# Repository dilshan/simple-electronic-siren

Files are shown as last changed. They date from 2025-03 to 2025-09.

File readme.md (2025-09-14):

# Simple Transistor-Based Electronic Siren

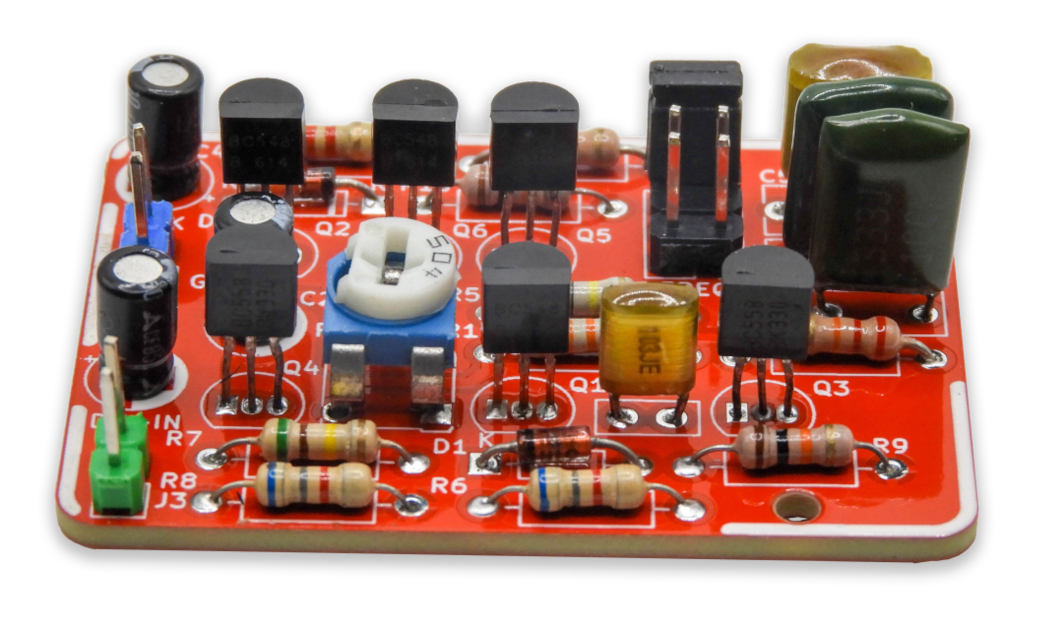
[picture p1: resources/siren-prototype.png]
Finished prototype build of the electronic siren


This project provides a discrete transistor implementation of a multi-tone electronic siren, offering an easy-to-build and low-cost solution that replicates alarm effects found in classic two-timer NE556 siren circuits. It serves as a practical alternative to rare *UM3561* and *UM3562* sound generator ICs.

The design uses only standard *BC548* / *BC558* transistors, resistors, and capacitors—making it easy to build with commonly available components.

A full assembly and test demonstration is available on [YouTube](https://youtu.be/mPkqBXPQGk4). Full details of this project are available at [blog post in here](https://jayakody2000lk.blogspot.com/2025/09/a-simple-transistor-based-electronic.html). 

---

## Features
- Three siren effects
- Adjustable sweep rate via potentiometer
- Operates from **6V** - **12V DC** supply
- Drives a small speaker (16Ω – 32Ω)
- All through-hole components for easy assembly

## PCB
This project PCB was sponsored by **PCBWay**. You can [order the PCB directly from PCBWay’s project sharing space](https://www.pcbway.com/project/shareproject/W282856ASV37_electronic_siren_09_07_2025_0b272f0c.html).

## License
This project is released under the [**Creative Commons Attribution 4.0 International**](https://github.com/dilshan/simple-electronic-siren#CC-BY-4.0-1-ov-file).

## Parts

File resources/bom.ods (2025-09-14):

Designator | Value | Datasheet | Footprint | Qty | Store Link
C1 | 0.033μF | ~ | Capacitor/THT | 1 | https://s.click.aliexpress.com/e/_oDdgOUJ
C2 | 2.2μF / 25V | ~ | Capacitor/THT | 1 | https://s.click.aliexpress.com/e/_oo8At3v
C3 | 0.047μF | ~ | Capacitor/THT | 1 | https://s.click.aliexpress.com/e/_oDdgOUJ
C4,C7 | 10μF / 25V | ~ | Capacitor/THT | 2 | https://s.click.aliexpress.com/e/_oo8At3v
C5 | 0.1μF | ~ | Capacitor/THT | 1 | https://s.click.aliexpress.com/e/_oDdgOUJ
C6 | 0.01μF | ~ | Capacitor/THT | 1 | https://s.click.aliexpress.com/e/_oDdgOUJ
D1,D2 | 1N4148 | https://assets.nexperia.com/documents/data-sheet/1N4148_1N4448.pdf | DO-35 | 2 | https://s.click.aliexpress.com/e/_o2cQ6e7
J1 | 2.54mm 2x3-Pin Header | ~ | Pin Header 2.54mm 2 x 03 | 1 | https://s.click.aliexpress.com/e/_oCfAScX
J2,J3 | 2.54mm 2-Pin Header | ~ | Pin Header 2.54mm 1 x 02 | 2 | https://s.click.aliexpress.com/e/_oCLhFeR
Q1,Q2,Q6 | BC548 | https://www.onsemi.com/pub/Collateral/BC550-D.pdf | TO-92 | 3 | https://s.click.aliexpress.com/e/_onDyZFh
Q3,Q4,Q5 | BC558 | https://www.onsemi.com/pub/Collateral/BC556BTA-D.pdf | TO-92 | 3 | https://s.click.aliexpress.com/e/_onDyZFh
R1 | 33KΩ | ~ | 1/4W Resistor/THT | 1 | https://s.click.aliexpress.com/e/_oEG9d83
R2,R3 | 22KΩ | ~ | 1/4W Resistor/THT | 2 | https://s.click.aliexpress.com/e/_oEG9d83
R4 | 2.2KΩ | ~ | 1/4W Resistor/THT | 1 | https://s.click.aliexpress.com/e/_oEG9d83
R5 | 100KΩ | ~ | 1/4W Resistor/THT | 1 | https://s.click.aliexpress.com/e/_oEG9d83
R6,R8 | 6.8KΩ | ~ | 1/4W Resistor/THT | 2 | https://s.click.aliexpress.com/e/_oEG9d83
R7 | 150KΩ | ~ | 1/4W Resistor/THT | 1 | https://s.click.aliexpress.com/e/_oEG9d83
R9,R10 | 10KΩ | ~ | 1/4W Resistor/THT | 2 | https://s.click.aliexpress.com/e/_oEG9d83
RV1 | 500KΩ | ~ | RM-065 Vertical | 1 | https://s.click.aliexpress.com/e/_oEEE6pv
SPK1 | 16Ω – 32Ω Speaker | ~ | ~ | 1 | https://s.click.aliexpress.com/e/_oCOTR2n
J1-CAP | Jumper Cap |  | 2.54mm Jumper Cap | 1 | https://s.click.aliexpress.com/e/_oCLhFeR

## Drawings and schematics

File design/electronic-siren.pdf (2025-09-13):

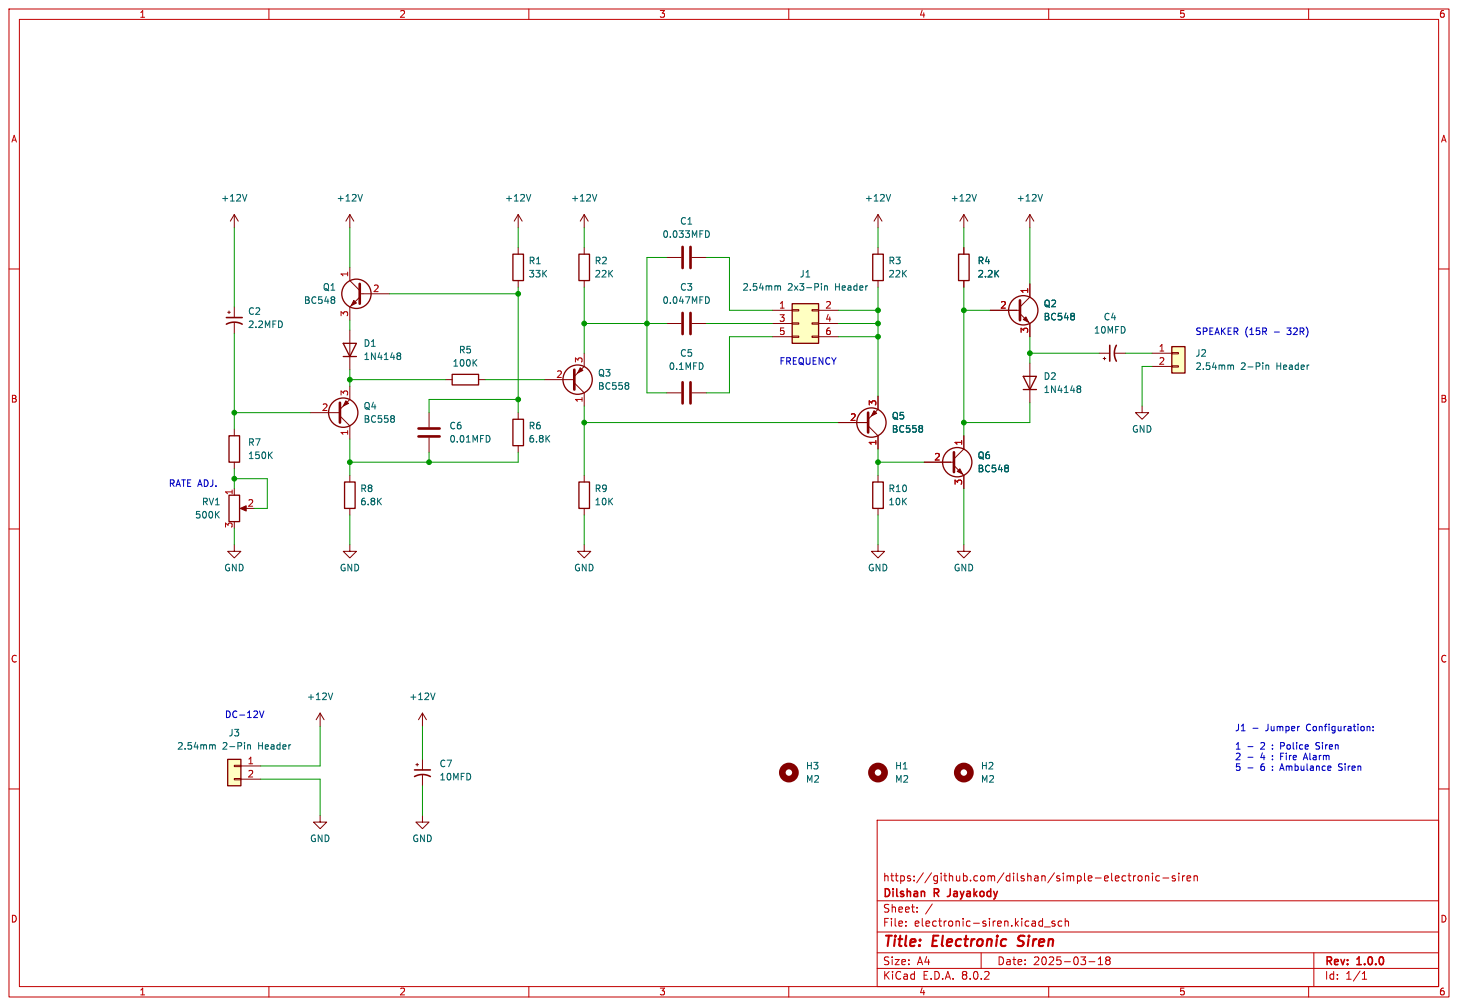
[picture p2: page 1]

https://github.com/dilshan/simple-electronic-siren R8

Id: 1/1 Title: Electronic Siren

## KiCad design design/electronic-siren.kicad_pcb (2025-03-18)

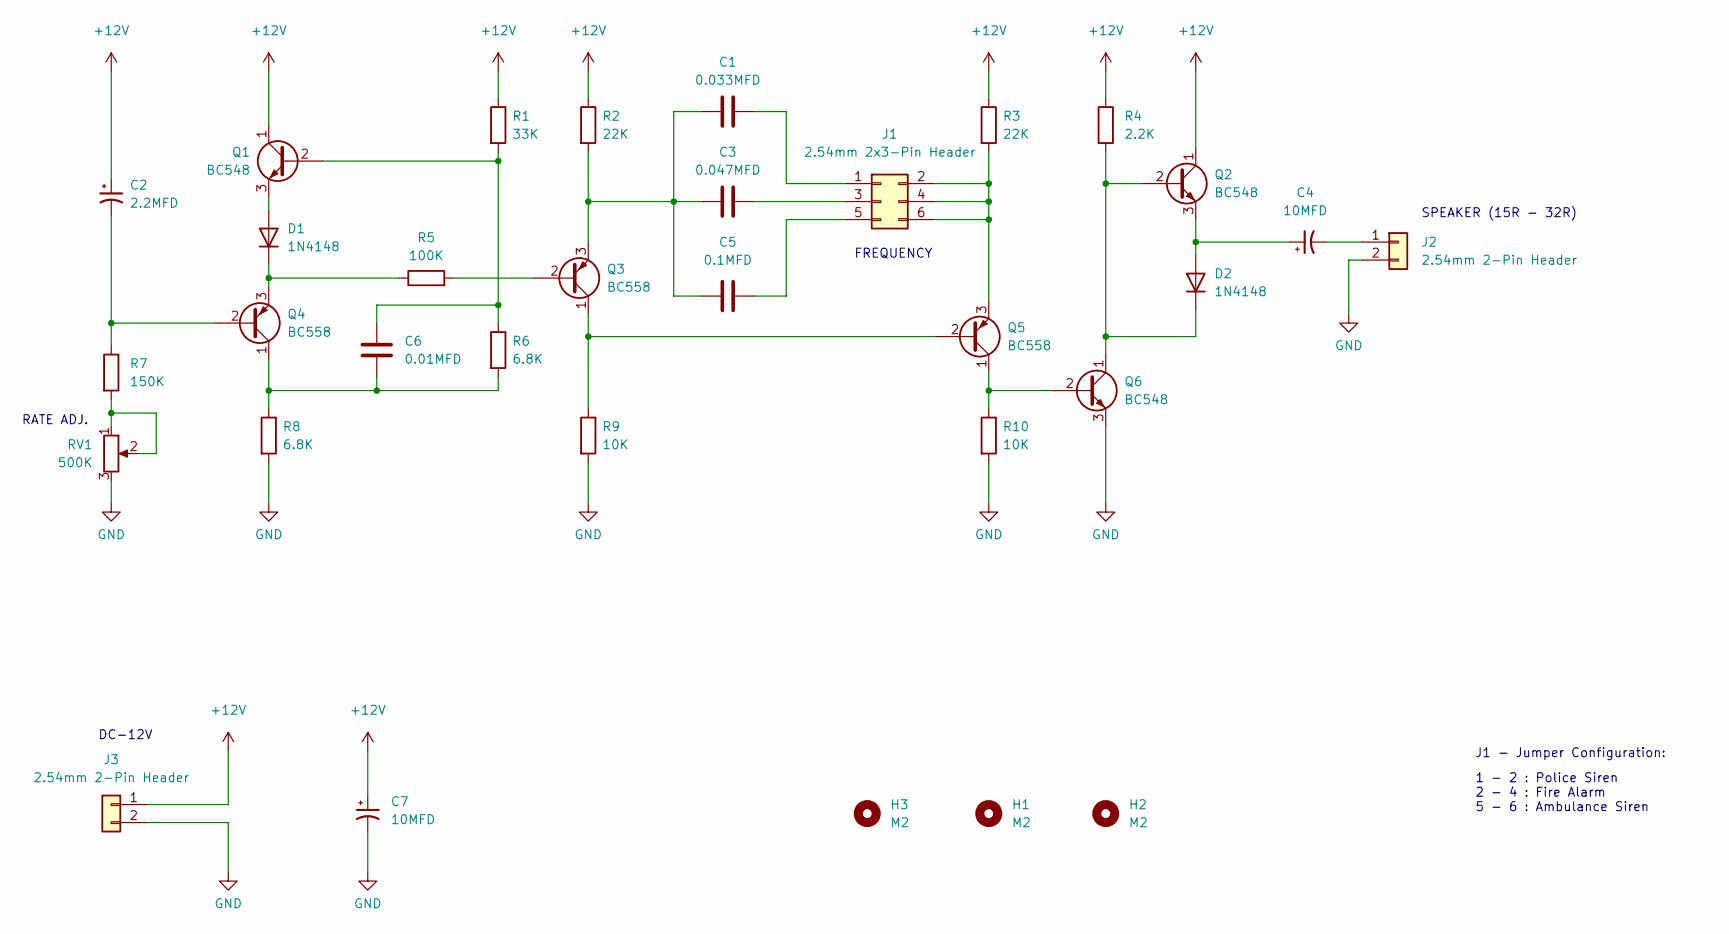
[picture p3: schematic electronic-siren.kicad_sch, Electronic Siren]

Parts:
C1: 0.033MFD; C_Rect_L7.0mm_W3.5mm_P5.00mm
C2: 2.2MFD; CP_Radial_D5.0mm_P2.00mm
C3: 0.047MFD; C_Rect_L9.0mm_W3.6mm_P7.50mm_MKT
C4, C7: 10MFD; CP_Radial_D5.0mm_P2.00mm
C5: 0.1MFD; C_Rect_L9.0mm_W4.2mm_P7.50mm_MKT
C6: 0.01MFD; C_Disc_D5.0mm_W2.5mm_P2.50mm
D1, D2: 1N4148; D_DO-35_SOD27_P7.62mm_Horizontal
H1, H2, H3: M2; MountingHole_2.2mm_M2
J1: 2.54mm 2x3-Pin Header; PinHeader_2x03_P2.54mm_Vertical
J2, J3: 2.54mm 2-Pin Header; PinHeader_1x02_P2.54mm_Vertical
Q1, Q2, Q6: BC548; TO-92_Inline
Q3, Q4, Q5: BC558; TO-92_Inline
R1: 33K; R_Axial_DIN0207_L6.3mm_D2.5mm_P10.16mm_Horizontal
R2, R3: 22K; R_Axial_DIN0207_L6.3mm_D2.5mm_P10.16mm_Horizontal
R4: 2.2K; R_Axial_DIN0207_L6.3mm_D2.5mm_P10.16mm_Horizontal
R5: 100K; R_Axial_DIN0207_L6.3mm_D2.5mm_P10.16mm_Horizontal
R6, R8: 6.8K; R_Axial_DIN0207_L6.3mm_D2.5mm_P10.16mm_Horizontal
R7: 150K; R_Axial_DIN0207_L6.3mm_D2.5mm_P10.16mm_Horizontal
R9, R10: 10K; R_Axial_DIN0207_L6.3mm_D2.5mm_P10.16mm_Horizontal
RV1: 500K; Potentiometer_Runtron_RM-065_Vertical

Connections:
+12V: C2.1, C7.1, J3.1, Q1.1 (C), Q2.1 (C), R1.1, R2.1, R3.1, R4.1
GND: C7.2, J2.2, J3.2, Q6.3 (E), R8.2, R9.2, R10.2, RV1.3
unnamed: D1.2 (A), Q1.3 (E)
unnamed: D1.1 (K), Q4.3 (E), R5.1
unnamed: C4.1, D2.2 (A), Q2.3 (E)
unnamed: D2.1 (K), Q2.2 (B), Q6.1 (C), R4.2
unnamed: C1.2, J1.1
unnamed: J1.2, J1.4, J1.6, Q5.3 (E), R3.2
unnamed: C3.2, J1.3
unnamed: C5.2, J1.5
unnamed: C4.2, J2.1
unnamed: C6.1, Q1.2 (B), R1.2, R6.1
unnamed: Q3.2 (B), R5.2
unnamed: Q3.1 (C), Q5.2 (B), R9.1
unnamed: C1.1, C3.1, C5.1, Q3.3 (E), R2.2
unnamed: C2.2, Q4.2 (B), R7.1
unnamed: C6.2, Q4.1 (C), R6.2, R8.1
unnamed: Q5.1 (C), Q6.2 (B), R10.1
unnamed: R7.2, RV1.1, RV1.2

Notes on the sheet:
DC-12V
RATE ADJ.
FREQUENCY
SPEAKER (15R - 32R)
1 - 2 : Police Siren 2 - 4 : Fire Alarm 5 - 6 : Ambulance Siren
J1 - Jumper Configuration:

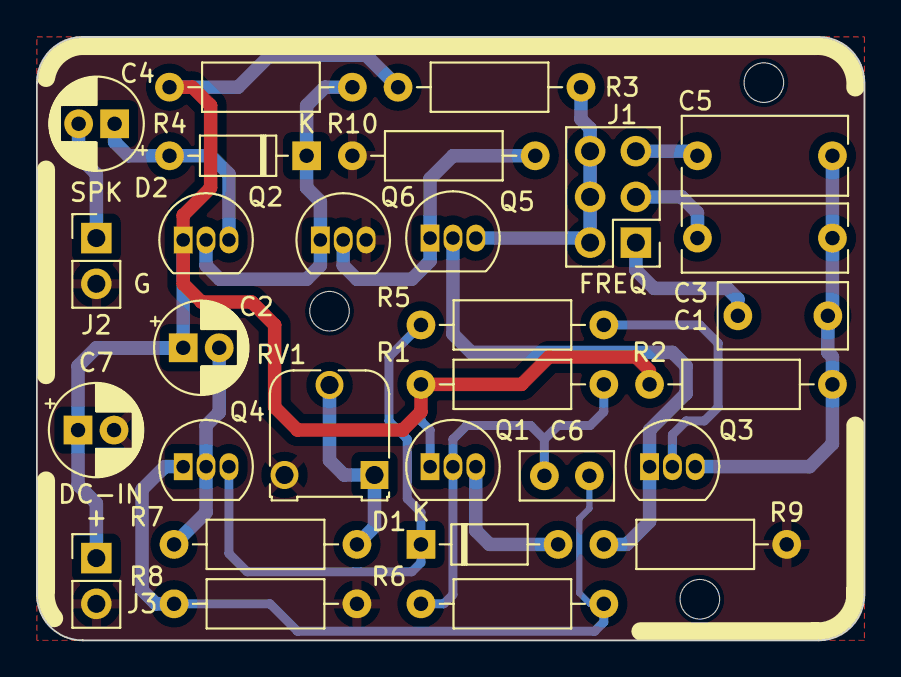
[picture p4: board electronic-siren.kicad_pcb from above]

Board: 2 copper layers, 46.0 x 33.5 mm, 32 parts (0 on the bottom side), 19 nets.

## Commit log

2025-03-18 Add initial version of design files.
    [electronic-siren.kicad_pcb, electronic-siren.kicad_sch]
2025-09-13 Add schematic in PDF format.
2025-09-13 Add image of the prototype build.
2025-09-13 Add BoM.
    [bom.ods]
2025-09-13 Update BoM with standard component names.
    [bom.ods]
2025-09-14 Add PCBWay order link to readme file.
2025-09-14 Fix column name issue in BoM
    [bom.ods]
